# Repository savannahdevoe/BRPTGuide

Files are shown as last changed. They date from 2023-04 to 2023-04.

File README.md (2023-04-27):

# BRPTGuide
How-to-guide, user manual, and miscellaneous files to construct and operate a BRPT (Blue Robotics Pressure and Temperature) instruments for measuring water temperature (C) and pressure (mbar). The BRPT samples at a rate of ~16 Hz and may be deployed (in its current design) for a period of 4-10 days (depending on battery capacity and environmental conditions) in up to 10 m of water depth. Original instrument designed, fabricated, and tested by Spencer Marquardt, M.S. (UNH '22G).

PLEASE READ THE DISCLAIMERS AT THE END OF THIS README.

PURPOSE: This repository contains information and instructions on how to construct and operate a novel pressure/temperature instrument to collect environmental data. BRPTs have primarily been utilized and tested in nearshore/wave-current climates to observe swash zone, wave, and flooding dynamics. The BRPT may also be appropriate for other applications and in various environments.

FILES: This repository contains the following directories.
  Arduino        — This directory contains the Arduino .ino sketch to control the Teensy microcontroller and BlueRobotics sensors. The associated libraries                    (for the pressure and temperature sensor) are also included. Source code in these libraries has been modified to work with the BRPT .ino                    sketch.
  AssemblyGuide  - This directory contains the overview document for how to construct the BRPT and its various components. Note, this assembly guide                          provides instructions for creating BRPTs using the 1ST GENERATION BlueRobotics acrylic Series 3 housing and end caps, which has been                        DISCONTINUED at the time of upload. Document needs to be updated to reflect newer designs using 2nd Generation BlueRobotics housings and                    end caps and/or custom housing designs using PVC or other material.
  CAD_3DPrinting - This directory contains CAD files to generate a 3D SolidWorks model of the BRPT with the 1ST GENERATION acrylic housing and end caps.                      Files are also included for the 3D-printed components required to assemble the battery housing. CAD drawings are provided to show                          modifications required for the BlueRobotics end caps (3 hole end cap plate is CUSTOM machined part) and the BlueRobotics 1st Gen housing                    (to add threaded inserts to the end walls for more secure fastening of end caps to the housing body, as well as boring out the inner                        diameter of the 1st Gen housing to ensure a uniform contact surface for the end cap o-rings).
  OpsManual      - This directory contains the operations manual ("Quick Start Guide") providing instructions for how to prepare the circuit, battery                          housing, external housing, and end caps for deployment of the 1ST GENERATION acrylic housing BRPT. The document also briefly explains                      the data retrieval and conversion process at the conclusion of data collection.
  PartsList      - This directory contains a spreadheet of materials required to construct the BRPTs. It has been updated to reflect materials required for                    the NEW 2ND GENERATION locking-flange acrylic housings and end caps provided by BlueRobotics at the time of publication (April 2023). T                    This list should be reviewed thoroughly by the user prior to being utilized to purchase supplies to construct a BRPT.
  PCB            - This directory contains the files required to print a custom printed circuit board.
  SLERJ_Logger   - This directory contains information about the multi-channel serial datalogger used in the BRPT, including a general setup and data                          conversion guide. A brief overview of the specific steps required for setup and data conversion with the BRPTs is also included in the                      Quick Start Guide in the OpsManual directory.

DISCLAIMERS:
1. THIS REPOSITORY IS STILL BEING EDITED, UNLESS NOTED OTHERWISE.
2. All files (guides, documents, codes, etc.) in this repository may contain unintentional errors and should be considered as DRAFT documents. Please thoroughly review them and follow instructions or suggestions at your own discretion.
3. Instructions and designs contained herein are works in progress, and as such, span a range of part generations, design iterations, etc. and are not finalized unless noted otherwise.
4. This repository is meant to serve as an educational resouce for the construction of BRPT (pressure/temperature) instruments and is not intended to provide a foolproof, commercial-quality instrument. 

Thank you in advance for your interest and understanding!
Savannah DeVoe
Coastal Processes Lab
School of Marine Science & Ocean Engineering
University of New Hampshire

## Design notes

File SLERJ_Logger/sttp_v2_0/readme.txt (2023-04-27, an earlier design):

Version 2.0 - 2 Mar 2019 (see changelog below)

The SLERJ Time Tagged Parser is a Windows command line utility (sttp.exe) 
provided with the SSR loggers to parse time tagged archives into various
output types.  Given a time tagged archive, the utility can produce a
variety of output files including:
  => the original raw stream (with no timing information),
  => timestamped text lines (for archives of recorded text data),
  => and detailed contents of the archive to include:
     - a time correlation packet file,
     - a data packet file that has a line for each data frame,
     - and a mixed file that interlaces time correlation with data packets.

***** NEW WITH VERSION 2.0 *****
Version 2 of STTP now supports user defined scripts to parse payload data
with reference to the SSR timestamps embedded in time tagged archives.
Check out the Lua scripts in the examples subfolder.

For timestamped-line output, the format of the time stamp can be specified
using any of the identifiers used by the standard C89 library function strftime.
A list is provided below for reference.

For the detailed archive content output (options -t, -d, and -m), data bytes 
are represented as a series of hexadecimal text characters. An example of each 
of the output files is below.   Usage of the sttp utility is summarized by 
its help output:

usage: sttp.exe [options] <infile>
    Version 2.0, Mar  2 2019 11:05:21
    options:
      -h                Include headers in tcp and dat files.
      -r <raw_file>     Write raw stream data to raw_file
      -x <lua_file>     Send data to an external lua script for parsing
      -t <tcp_file>     Write Time Correlation Packets to tcp_file
      -d <dat_file>     Write Tagged data to dat_file
      -m <mxd_file>     Write both TCPs and tagged data to mxd_file
      -n <txt_file>     Write timestamped line text file
      -N "string"       Date format string for tagged line output (strftime)
      -S                Suppress milliseconds in tagged line output
      --nointerp        Use pre-v1.6 behavior, not interpolating timestamps in -n output
      --dat-bpl         Modified Tagged data (-d) output to give one data byte per line
    Interval extraction options for timestamped line output:
         For the arguments below, 'N' is assumed to be in seconds unless suffixed with 'L', which
         denotes lines.  For example '-i 30' denotes an interval of 30 seconds, where '-i 30L' denotes
         an interval of 30 timestamped lines of data.
      -k,--skip N       Skip N seconds/lines of data before producing output
      -i,--interval N   Extract excerpts at intervals of N seconds/lines
      -w,--window N     Extract N seconds/lines at each interval
      -v,--nwins M      Process M windows (default=0, which means to end of file)

Timestamped-line text output:
  Note that for timestamped-line output, each line that contains data will be
  prepended by a date string as determined by the specified format (or the
  default format "%Y %m %d %H %M %S "), followed by the three digit millisecond
  portion of the timestamp, followed by the contents of the line.  The time
  stamp prepended to the line corresponds to the time of the 2ms cycle in
  which the first character of the line was received.

  Consider an example in which the following text output is recorded:
    S D  0.0000122 kg
    S D  0.0000122 kg
    S D  0.0000122 kg
    S D  0.0000123 kg

  Timestamped-line text output example using the default format:
    2014 02 03 21 47 38 915 S D  0.0000122 kg
    2014 02 03 21 47 39 013 S D  0.0000122 kg
    2014 02 03 21 47 39 111 S D  0.0000122 kg
    2014 02 03 21 47 39 207 S D  0.0000123 kg

  Timestamped-line text output example using -N "%m/%d/%Y %H:%M:%S.":
    02/03/2014 21:47:38.915 S D  0.0000122 kg
    02/03/2014 21:47:39.013 S D  0.0000122 kg
    02/03/2014 21:47:39.111 S D  0.0000122 kg
    02/03/2014 21:47:39.207 S D  0.0000123 kg

Time Correlation Packet output example:
    RunTime(ms) Year Month Day Hour Minute Second
    4196 2013 3 25 9 52 4.625
    604196 2013 3 25 10 2 3.628
    1204196 2013 3 25 10 12 2.486

Tagged Data output example:
    RunTime(ms) count HexBytes
    4196 20 322E323530333630652B303520322E3339343433
    4198 23 30652D3034202D312E343530303639652D303420322E37
    4200 23 3637343235652D303420312E373134373036652D303120

Mixed output example:
    A3 4196 2013 3 25 9 52 4.625
    A2 4196 20 322E323530333630652B303520322E3339343433
    A2 4198 23 30652D3034202D312E343530303639652D303420322E37
    …
    A2 604194 23 3032202D352E353633313634652D303120312E32323636
    A3 604196 2013 3 25 10 2 3.628
    A2 604196 23 3330652D303220332E313334343333652B303020302037

Timestamped-line mode format options
  For timestamped-line mode, the specific form of the timstamp may be specified
  on the command line with the -N option.  For example, to add a timestamp of
  the form yyyy-mm-dd hh:mm:ss.msec, add to the command line:
     -N "%Y-%m-%d %H:%M:%S."
  The % fields are the same as those defined for the standard C library
  function strftime.  The most common are listed below.  Unless -S is specified
  on the sttp command line to suppress the milliseconds field, the three digit 
  value of milliseconds will immediately follow the result of the format string.  
  In the example above, the period at the end of the string serves as the  
  decimal in the fractional seconds field that results.  An example of lines  
  generated using this format string and no -S would be:
      2014-02-03 21:47:38.915 S D  0.0000122 kg
      2014-02-03 21:47:39.013 S D  0.0000122 kg
      2014-02-03 21:47:39.111 S D  0.0000122 kg
      2014-02-03 21:47:39.207 S D  0.0000123 kg

  Common timestamp format fields:
   Field Example
    %b   Aug                       Abbreviated month name
    %B   August                    Full month name
    %c   Thu Aug 23 14:55:02 2001  Date and time representation
    %d   23                        Day of the month, zero-padded (01-31)
    %H   14                        Hour in 24h format (00-23)
    %I   02                        Hour in 12h format (01-12)
    %j   235                       Day of the year (001-366)
    %m   08                        Month as a decimal number (01-12)
    %M   55                        Minute (00-59)
    %p   PM                        AM or PM designation
    %S   02                        Second (00-61)
    %x   08/23/01                  Date representation
    %X   14:55:02                  Time representation
    %y   01                        Year, last two digits (00-99)
    %Y   2001                      Year
    %%                             A % sign  %

In version 2, the -x option has been added to send the packet data to a Lua
script for parsing.  The script must define the function:
  ParseData(runtime,timestamp,data)
The lua script is executed when it is loaded, allowing parser state to be 
initialized and output file(s) to be opened as required.  Then the ParseData
function will be called for each time tagged data packet in the archive, and
will receive the packet runtime (in msec), a formatted timestamp based on the
SSR real time clock using the provided strftime format string, and the bytes
stored in the time tagged data packet.

The Lua Environemnt provides a couple of additional functions that can
reach back into STTP.
  sttp_setTSFormat(string fmt, bool SuppressMSec)
      This function allows the timestamp format string to be provided in
      the lua script instead of on the sttp command line using -N.  The
      second argument replaces the command line argument -S.  This function
      overrides the command line arguments.
  sttp_getPaths()
      This function returns a table with useful path information.  Fields
      of the table are:
      ArchiveFile - the full, absolute path of the archive file being parsed
      ArchivePath - the directory of the archive file
      ArchiveName - the name of the archive file (without path or extension)
      ArchiveExt  - the archive file extension
      cwd         - the STTP current working directory.

See the Lua examples for details on how to use these. 

==============================================================================
ChangeLog
---------
Version 2.0 - 2 Mar 2019
  Added Lua script engine to support external, application specific data
  parsers.  This allows binary data stored in a time tagged archive to be
  parsed with the SSR clock information available for reference.  See the
  lua examples for detials.

Version 1.7 - 7 Feb 2019
  Added an option --dat-bpl to change the -d (dat file) output to give
  one byte per line so that each line has only RunTime and a single byte.
  
Version 1.6 - 15 Mar 2018
  Reworked timestamped-line output to interpolate the RTC based timestamp to 
  compensate for drift of the free running msec clock used to tag data packets.

  Added the option --nointerp to revert to the original behavior. 
  
Version 1.5 - 21 Feb 2018
  Added support for time tagged archives recorded at high data rates and
  bandwidth (>635 kbaud).  This corresponds to a fix in SSR-1 firmware
  v1.2.1.

Version 1.4 - 10 Aug 2017
  Added options to decimate timestamp line output (only output at intervals).
  
Version 1.3 - 4 Feb 2017
  Corrected bug that caused high baud recordings (>315k baud) to fail parsing.
  
Version 1.2 - 10 May 2016
  Corrected bug where -n option was looking for 0xC as newline instead of 0xD
  
Version 1.1 - 19 Feb 2015
  Added timestamped-line mode for text data recorded in an archive.

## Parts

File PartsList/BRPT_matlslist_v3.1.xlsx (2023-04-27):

DISCLAIMER: THIS SHEET CONTAINS A MIXTURE OF SUGGESTED AND REQUIRED MATERIALS TO CONSTRUCT THE BRPT INSTRUMENT. Prices and availability shown as of September 2022. Items should be purchased at your own discretion. Cells and prices are meant to change automatically depending on the number of NEW BRPTs you want to make (specified in J6) and spare circuitry/battery components you wish to make (specified in J2), but should be verified by the reader prior to making purchases. |  |  |  |  |  |  |  | SPARES? | 2 | num of spare circuitry components (e.g., sensors, PCBs, etc.)
Rev 2.0 | Savannah DeVoe | 2023-04-01
Item # | Note and/or BRPT Version | Part Name | Part Description | Company | PartNnumber (SKU) | Price | Unit | QTY Have | QTY Need | QTY To Purchase | Subtotal | Link
1 | INPUT QTY OF BRPTs YOU WANT TO MAKE IN THIS ROW, AND ALL OTHERS SHOULD POPULATE | Acrylic Pipe | 3" series cast acrylic 300mm (11.8") length, 150 m depth rating, 75mm (3") dia. | Blue Robotics | WTE3-P-LOCKING-TUBE-300-R2-RP | $215.00 | /EA | 0 | 2 | 2 | $430.00 | https://bluerobotics.com/store/watertight-enclosures/locking-series/wte-locking-tube-r1-vp/
2 | v3.1 only | O-Ring Flange | 75 mm (3") dia., comes with o-rings and screws | Blue Robotics | WTE3-M-LOCKING-FLANGE-SEAL-R1-RP | $35.00 | /EA | 0 | 4 | 4 | $140.00 | https://bluerobotics.com/store/watertight-enclosures/locking-series/wte-flange-vp/
3 | CHOOSE EITHER 3 OR 4. v3.1 and v3.2 | Blank Acrylic End Cap | End Cap - Acrylic - Blank - 400 m 75 mm (3") dia. | Blue Robotics | WTE3-P-END-CAP-R1-RP | $15.00 | /EA | 0 | 0 | 0 | $0.00 | https://bluerobotics.com/store/watertight-enclosures/locking-series/wte-end-cap-vp/
4 |  | Blank Aluminum End Cap | End Cap - Aluminum - Blank - 950 m 75 mm (3") dia. | Blue Robotics | WTE3-M-END-CAP-R1-RP | $14.00 | /EA | 0 | 8 | 8 | $112.00 | https://bluerobotics.com/store/watertight-enclosures/locking-series/wte-end-cap-vp/
5 | Not a totally necessary part (we machine item 2 or 3 to have 3 holes) but it's here for reference. V3.1 and v3.2 | 4 Hole Aluminum End Cap | End Cap - Aluminum - 4 Holes - 950 m 75 mm (3") dia. | Blue Robotics | WTE3-M-END-CAP-4-HOLE-R1-RP | $14.00 | /EA | 0 | 0 | 0 | $0.00 | https://bluerobotics.com/store/watertight-enclosures/locking-series/wte-end-cap-vp/
6 | NOTE: This part optional. We will use backflow prevention valves (see below) instead of the enclosure vent and plug for Foster Lab BRPTsv3.1 and v3.2 | Enclosure Vent and Plug | M10 Enclosure Vent and Plug | Blue Robotics | VENT-M10-R1-RP | $9.00 | /EA | 0 | 4 | 4 | $36.00 | https://bluerobotics.com/store/cables-connectors/penetrators/vent-asm-r1/
7 | v3.1 and v3.2 | Pressure Sensor | Bar02 Ultra High Resolution 10m Depth/Pressure Sensor | Blue Robotics | BAR02-SENSOR-R2-RP | $75.00 | /EA | 0 | 4 | 4 | $300.00 | https://bluerobotics.com/store/sensors-sonars-cameras/sensors/bar02-sensor-r1-rp/
8 | v3.1 and v3.2 | Temperature Sensor | Celsius Fast-Response, ±0.1°C Temperature Sensor (I2C) | Blue Robotics | CELSIUS-SENSOR-R2-RP | $70.00 | /EA | 0 | 4 | 4 | $280.00 | https://bluerobotics.com/store/sensors-sonars-cameras/sensors/celsius-sensor-r1/
9 | NOTE: This part optional. We will use backflow prevention valves (see below) instead of the enclosure vent and plug for Foster Lab BRPTsv3.1 and v3.2 | Manual Vacuum Pump | Mityvac Hand Operated Vacuum Pump | Blue Robotics | VACUUM-PUMP-KIT-R4-RP | $98.00 | /EA | 0 | 0 | 0 | $0.00 | https://bluerobotics.com/store/watertight-enclosures/enclosure-tools-supplies/vacuum-pump-kit-r2-rp/
10 | NOTE: This part optional. We will use backflow prevention valves (see below) instead of the enclosure vent and plug for Foster Lab BRPTsv3.1 and v3.2 | Vacuum Plug | Adapter for vacuum pump | Blue Robotics | VENT-M10-VACUUM-PLUG-R1-RP | $8.00 | /EA | 0 | 0 | 0 | $0.00 | https://bluerobotics.com/store/watertight-enclosures/enclosure-tools-supplies/vacuum-plug/
11 | v3.1 only | Spare Locking Cord and Handles |  | Blue Robotics | WTE-LOCKING-CORD-SPARE-SET-R1-RP | $10.00 | /EA | 0 | 1 | 1 | $10.00 | https://bluerobotics.com/store/watertight-enclosures/locking-series/wte-locking-cord/
12 | v3.1 and v3.2 | Spare O-Ring Set | Spare O-ring Set 75 mm (3") dia. | Blue Robotics | WTE3-O-RING-SET-R2-RP | $3.00 | /EA | 0 | 2 | 2 | $6.00 | https://bluerobotics.com/store/watertight-enclosures/locking-series/spare-o-ring-set/
13 | v3.1 and v3.2 | Datalogger | SSR-LC Single Channel Serial Data Logger | SLERJ | SSRLC | $39.00 | /EA | 0 | 4 | 4 | $156.00 | https://www.slerj.com/ssr-lc.html
14 | v3.1 and v3.2 | microSD card | SanDisk Industrial MLC MicroSD SDHC UHS-I Class 10 SDSDQAF3-008G-I with SanDisk Adapter (8GB) | SanDisk; purchased via Amazon |  | $9.10 | /EA | 0 | 4 | 4 | $36.40 | https://www.amazon.com/SanDisk-Industrial-MicroSD-SDSDQAF3-008G-I-Adapter/dp/B07BZ5SY18
15 | v3.1 and v3.2. NOTE: 3D-printed battery holders are designed for particular battery length. | Batteries | 18650 2600mAH 3.7V battery | Dantona Industries; purchased via DigiKey | 3145-LION-1865-26-ND | $6.60 | /EA | 0 | 48 | 48 | $316.80 | https://www.digikey.com/en/products/detail/dantona-industries/LION-1865-26/13692661
16 | v3.1 and v3.2 | Voltage Regulator | IC Reg linear 5V 1.5A TO220-3 | DigiKey | Digi-Key Part Number: 296-39515-5-ND | $0.87 | /EA | 0 | 8 | 8 | $6.96 | https://www.digikey.com/en/products/detail/texas-instruments/UA7805CKCT/3458146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
17 | v3.1 and v3.2 | Battery Springs | Battery contact spring | DigiKey | 36-209-ND | $0.22 | /EA | 0 | 96 | 96 | $21.12 | https://www.digikey.com/en/products/detail/209/36-209-ND/151583?itemSeq=362037172
18 | v3.1 and v3.2 | On-Off Button | Tactile Switch Buttons (12mm square, 6mm tall) x 10 pack | Adafruit | 1119 | $2.50 | /EA | 0 | 1 | 1 | $2.50 | https://www.adafruit.com/product/1119
19 | v3.1 and v3.2 | Coin Cell Battery Board | 20mm Coin Cell Breakout Board (CR2032) | Adafruit | 1870 | $2.25 | /EA | 0 | 4 | 4 | $9.00 | https://www.adafruit.com/product/1870
20 | v3.1 and v3.2 | Teensy | Teensy 4.0 Microcontroller | Adafruit, purchased via DigiKey | Digi-Key Part Number: 1568-DEV-15583-ND | $21.88 | /EA | 0 | 4 | 4 | $87.52 | https://www.digikey.com/en/products/detail/sparkfun-electronics/DEV-15583/10384551
21 | v3.1 and v3.2 | Coin Cell Battery | CR2032 3.0V LITHIUM - PACK OF 5 | PKCell; purchased via DigiKey | 2375-CR2032-5B-ND | $1.00 | /EA | 0 | 1 | 1 | $1.00 | https://www.digikey.com/en/products/detail/pkcell/CR2032-5B/11629990
22 | v3.1 and v3.2 | Sensor Cable GH Connectors/Plugs | CQRobot 100 Sets/600 Pieces JST GH 1.25mm Pitch 4 Pin JST Connector Kit. JST 1.25mm Pitch Terminals, JST GH 4 Pin Housing JST Adapter Cable Connector Socket Male and Female, Crimp DIP Pins kit. | CQRobot, purchased via amazon | JST-GH1.25 GH 4P | $11.69 | /EA | 0 | 1 | 1 | $11.69 | https://www.amazon.com/CQRobot-Connector-Terminals-Housing-Adapter/dp/B0B3NB2PM8
23 | v3.1 and v3.2 | Battery/Jumper Cable JST Connectors/Plugs | 720Pcs 2.54mm JST-XHP 2/3 / 4/5 Pin Housing and Male Female Pin Header Connector Adapter Plug Set | FUNMANY; purchased via Amazon |  | $13.99 | /EA | 0 | 1 | 1 | $13.99 | https://www.amazon.com/gp/product/B0752C431F/ref=ox_sc_act_title_1?smid=A6QA7SV6MW7GH&psc=1
24 | v3.1 and v3.2 | Threaded Rod | 8-32 x 7" low-strength steel threaded rods, pk of 10 | McMaster-Carr | 91565A345 | $7.88 | /EA | 0 | 1 | 1 | $7.88 | https://www.mcmaster.com/91565A345/
25 | v3.1 and v3.2 | Wing Nut | 8-32x5/8x7/8 zinc alloy flanged wing nut, pk of 25 | McMaster-Carr | 92239A100 | $11.18 | /EA | 0 | 1 | 1 | $11.18 | https://www.mcmaster.com/92239A100/
26 | v3.1 and v3.2 | Standoff Screws | 4-40x1/2" long 3/16" aluminum male-female threaded hex standoff | McMaster-Carr | 93505A103 | $0.43 | /EA | 0 | 8 | 8 | $3.44 | https://www.mcmaster.com/93505A103/
27 | v3.1 and v3.2 | Flat Head Screws | 4-40x1/2" long 18-8 Stainless Steel Slotted Flat Head Screw, pk of 100 | McMaster-Carr | 91781A110 | $5.81 | /EA | 0 | 1 | 1 | $5.81 | https://www.mcmaster.com/91781A110/
28 | v3.1 and v3.2 | Hex Nut | 4-40 18-8 Stainless Steel Narrow Hex Nut, pk of 100 | McMaster-Carr | 90730A005 | $4.21 | /EA | 0 | 1 | 1 | $4.21 | https://www.mcmaster.com/90730A005/
29 | not really necessary (they come with the end caps), but good to have; v3.1 and v3.2 | End Cap Screw Replacements | M3x0.5-12 18-8 stainless steel socket head screw, pk of 100 | McMaster-Carr | 91292A114 | $6.00 | /EA | 0 | 0 | 0 | $0.00 | https://www.mcmaster.com/91292A114/
30 | v3.1 and v3.2 | End Cap Tap Screws | 4-40x3/4" long 18-8 stainless steel socket head screw, pk of 100 | McMaster-Carr | 92196A113 | $7.33 | /EA | 0 | 1 | 1 | $7.33 | https://www.mcmaster.com/92196A113/
31 | v3.1 and v3.2 | Threaded Inserts | 18-8 Stainless Steel Helical Insert, 4-40 Right-Hand Thread, 0.168" Long, pk of 10 | McMaster-Carr | 91732A285 | $5.70 | /EA | 0 | 2 | 2 | $11.40 | https://www.mcmaster.com/91732A285/
32 | v3.1 and v3.2 | Heat Shrink Tubing | Ginsco 580 pcs 2:1 Heat Shrink Tubing Kit 6 Colors 11 Sizes Assorted Sleeving Tube Wrap Cable Wire Kit for DIY | Ginsco, purchased via Amazon |  | $6.20 | /EA | 0 | 1 | 1 | $6.20 | https://www.amazon.com/Ginsco-580-pcs-Assorted-Sleeving/dp/B01MFA3OFA
33 | v3.1 and v3.2 | Resistors | EDGELEC 100pcs 10K ohm Resistor 1/4w (0.25 Watt) ±1% Tolerance Metal Film Fixed Resistor, Multiple Values of Resistance Optional | EDGELEC, purchased via Amazon | [E6P011] 10K ohm | $4.99 | /EA | 0 | 1 | 1 | $4.99 | https://www.amazon.com/EDGELEC-Resistor-Tolerance-Resistance-Optional/dp/B07HDGX5LM
34 | Note, exact cost per board is approximate and changes based on number ordered; v3.1 and v3.2 | PCB | Printed Circuit Board, multiples of 3 | Print on Aisler.net; Fritzing file is BRPT_v1.fzz; or gerber file is in BRPT_gerber.zip |  | $11.00 | /EA (mult of 5) | 0 | 2 | 2 | $22.00 | https://www.jlcpcb.com
35 | v3.1 and v3.2 | Wire | Striveday™Flexible Silicone Wire 22awg Electric Wire 22 Gauge Coper Hook Up Wire 300V Cables Electronic Stranded Wire Cable Electrics DIY Box-1 | Striveday, purchased via Amazon |  | $15.99 | /EA | 0 | 1 | 1 | $15.99 | https://www.amazon.com/StrivedayTM-Flexible-Silicone-electronic-electrics/dp/B01LH1FR6M
36 | this cable to be modified, used to connect circuit to PC; v3.1 and v3.2 | USB Cable | UGREEN USB to USB Cable, USB 3.0 Male to Male Type A to Type A Cable for Data Transfer Compatible with Hard Drive, Laptop, DVD Player, TV, USB 3.0 Hub, Monitor, Camera, Set Up Box and More 3FT | UGREEN, purchased via Amazon |  | $8.89 | /EA | 0 | 4 | 4 | $35.56 | https://www.amazon.com/dp/B00P0E39CM/ref=twister_B07CJ2Z4DZ?_encoding=UTF8&psc=1
37 | v3.1 and v3.2 | Epoxy | Structural Adhesive epoxy, Loctite 615 | McMaster Carr | 1813A246 | $18.26 | /EA | 0 | 1 | 1 | $18.26 | https://www.mcmaster.com/1813A246/
38 | v3.1 and v3.2 | Silicone sealant | Molykote 55 o-ring grease | McMaster-Carr | 1325K54 | $46.04 | /EA | 0 | 1 | 1 | $46.04 | https://www.mcmaster.com/1325K54/
39 | v3.1 and v3.2 | Battery charger | 8 Slots 18650 Battery Charger XTAR VC8 Charger USB C 3A Fast Charger 21700 Battery Charger with LCD Display for 3.6V 3.7V Li-ion 10440 18700 26650 1.2V Ni-MH AA AAA C Full Set with QC3.0 Wall Charger | XTAR, purchased via Amazon | VC8+QC3.0 Adapter | $40.00 | /EA | 0 | 2 | 2 | - | https://www.amazon.com/gp/product/B0836VHG67/ref=sw_img_1?smid=A3DHI68LB66BYX&th=1
40 | v3.1 and v3.2. NOTE: These used for particular deployment case. Different/additional materials are likely required for your particular deployment strategy. | Gasket sheet mcmaster |  |  | 1370N553 | $27.73 |  | 0 |  | 2 | 27.73
41 | v3.1 and v3.2. NOTE: These used for particular deployment case. Different/additional materials are likely required for your particular deployment strategy. | Screw anchors from amazon | MTB 30 Inches Auger Earth Anchor 3 Inches W Helix, 12mm Rod, Painted red, Heavy Duty Ground Anchor Hook for Guying Tents Fencing Canopies, Pack of 6 | Purchased via Amazon |  | $44.14 | /EA | 0 | 1 | 1 | 44.14 | https://www.amazon.com/MTB-Anchor-Painted-Fencing-Canopies/dp/B01MUZ9CLL
42 | v3.1 and v3.2. NOTE: These used for particular deployment case. Different/additional materials are likely required for your particular deployment strategy. | hose clamps | Worm-Drive Clamp for Firm Hose and Tube 316 Stainless Steel, 1/2" Band Width, 2-9/16"- 3-1/2" Clamp ID, pk of 5 | McMaster Carr | 5011T25 | $18.04 | /EA | 0 | 2 | 2 | $36.08 | https://www.mcmaster.com/5011T25/
43 | FOSTER LAB OPTION, v3.1 and v3.2 | Back Flow prevention valve | Brass Threaded Check Valve with Brass Spring-Loaded Piston, 1/8 NPTF Male | McMaster Carr | 7775K61 | $14.67 | /Ea | 0 | 4 | 4 | $58.68 | https://www.mcmaster.com/7775K61/
 |  |  |  |  |  |  |  | TOTAL COST: |  |  | $2131.23
 |  |  |  |  |  |  |  | UNIT COST |  |  | $1065.62

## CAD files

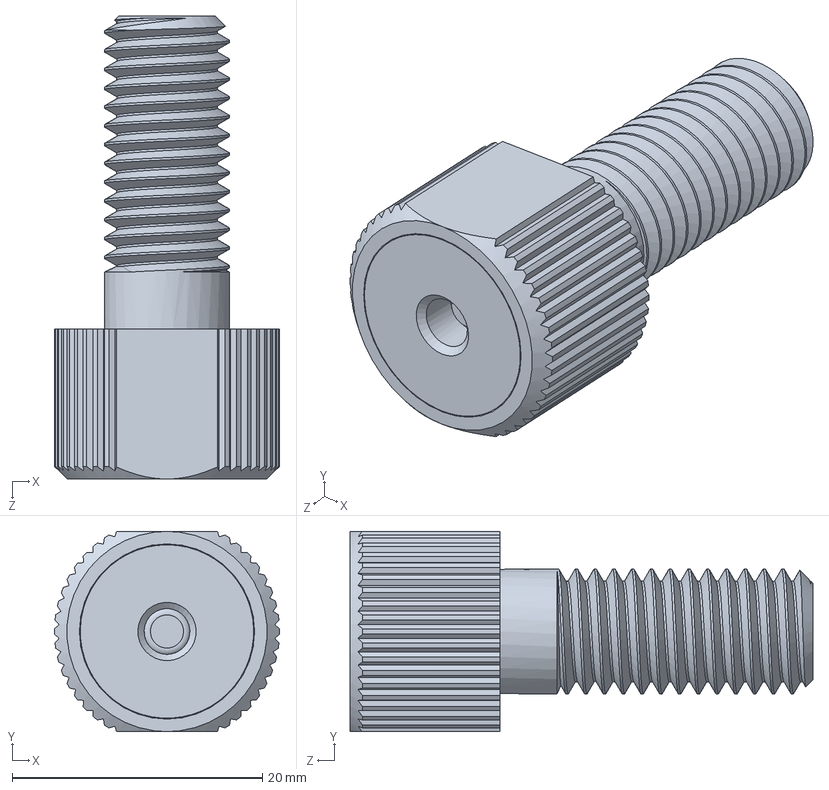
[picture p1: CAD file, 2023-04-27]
CAD_3DPrinting/Bar02/BAR30-SENSOR-ASSEMBLY-R1.SLDPRT
18.0 x 16.0 x 37.0 mm

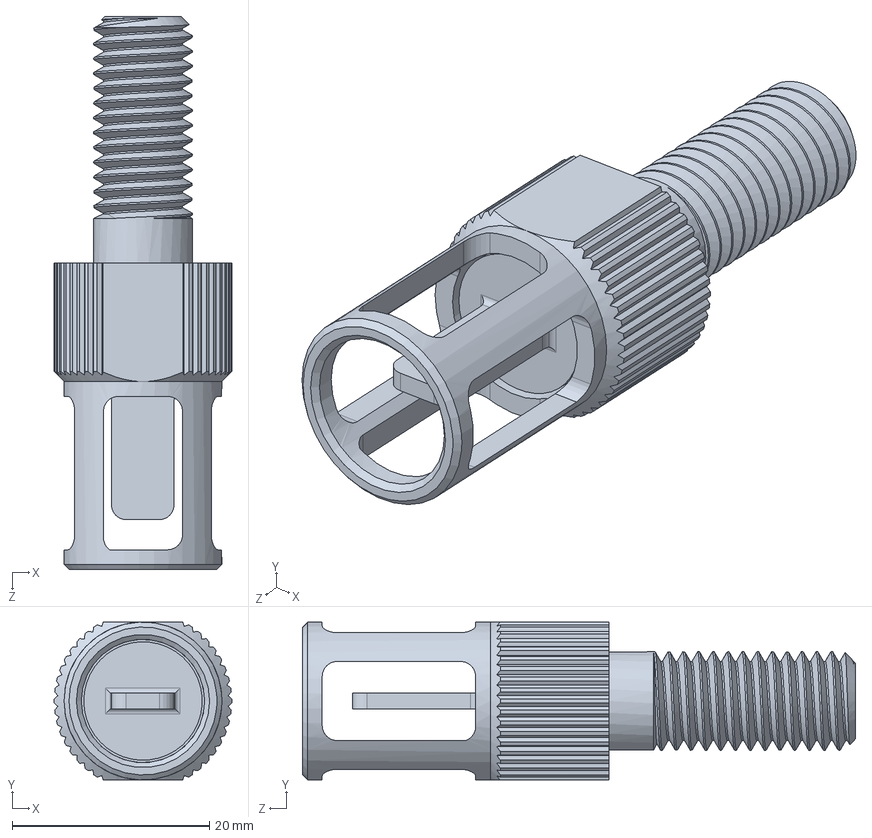
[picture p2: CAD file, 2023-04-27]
CAD_3DPrinting/Celcius temp sensor/CELSIUS-TEMPERATURE-SENSOR-ASSEMBLY-X1.SLDPRT
18.0 x 16.0 x 56.0 mm

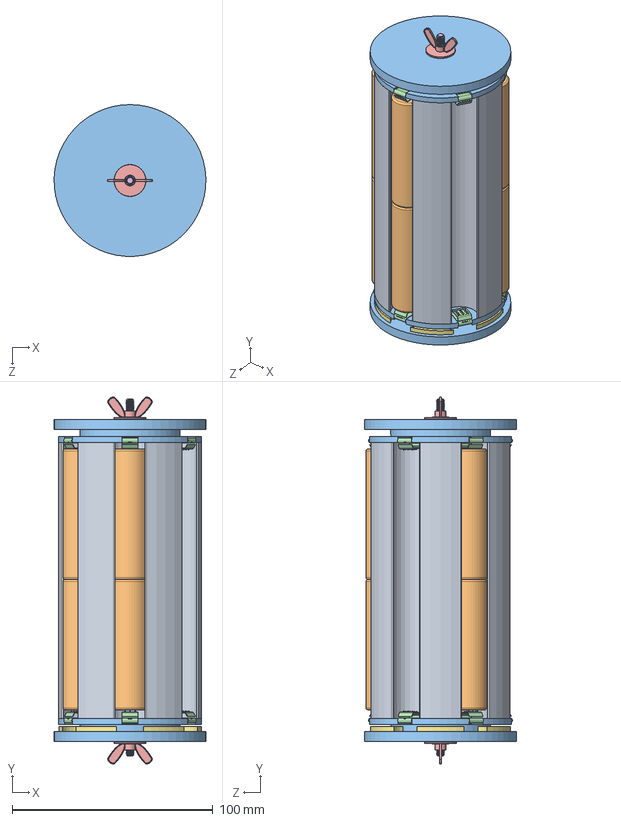
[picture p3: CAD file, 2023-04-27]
CAD_3DPrinting/Battery holder.SLDASM
75.7 x 182.9 x 75.7 mm
battery holder v2
2600mAh Battery x 8
Battery holder endcap x 2
battery contact 209 x 12
92239A100_FLANGED WING NUT x 2
91565A345_LOW-STRENGTH STEEL THREADED ROD

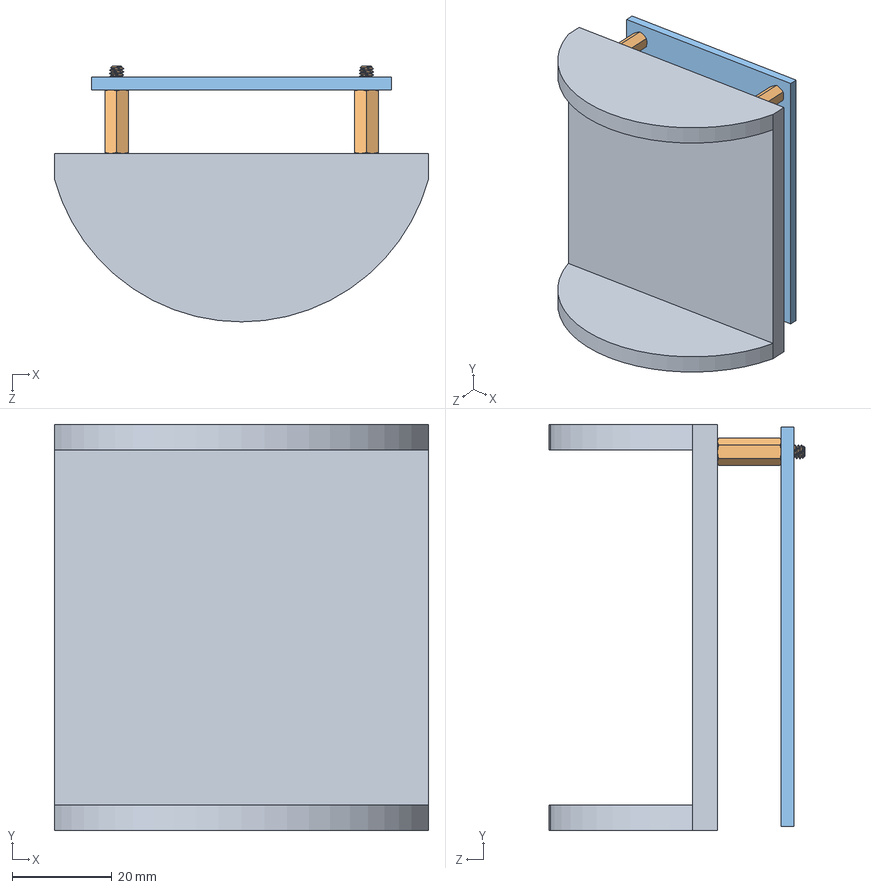
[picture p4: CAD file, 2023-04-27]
CAD_3DPrinting/Electronics Shelf.SLDASM
74.9 x 81.3 x 51.2 mm
Electronics Shelf
93505A103_MALE-FEMALE THREADED HEX STANDOFF x 2
PCB

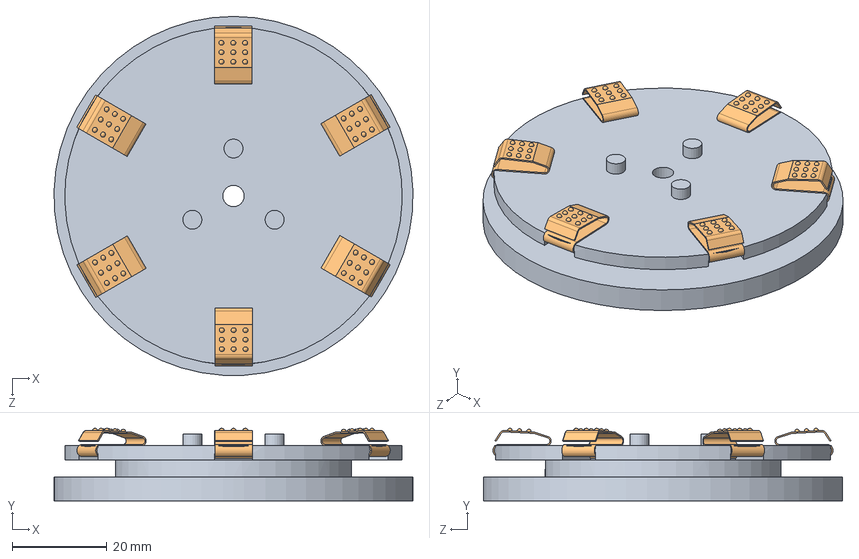
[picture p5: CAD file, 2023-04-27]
CAD_3DPrinting/Battery holder endcap.SLDASM
75.7 x 15.3 x 75.7 mm
Battery holder endcap
battery contact 209 x 6

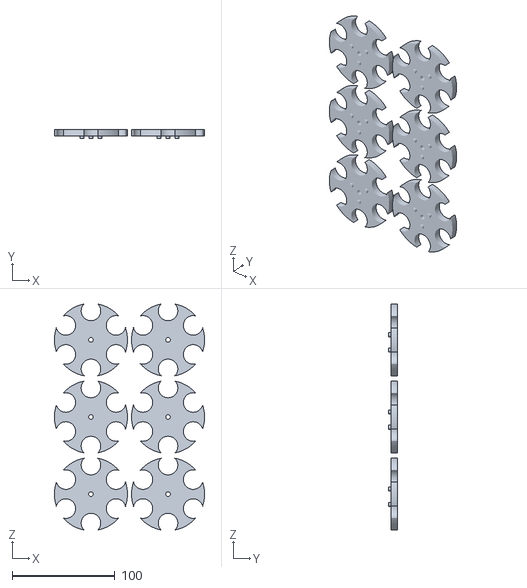
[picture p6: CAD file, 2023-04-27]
CAD_3DPrinting/3D print/Battery holder spacer 6.STL
146.1 x 9.00 x 219.8

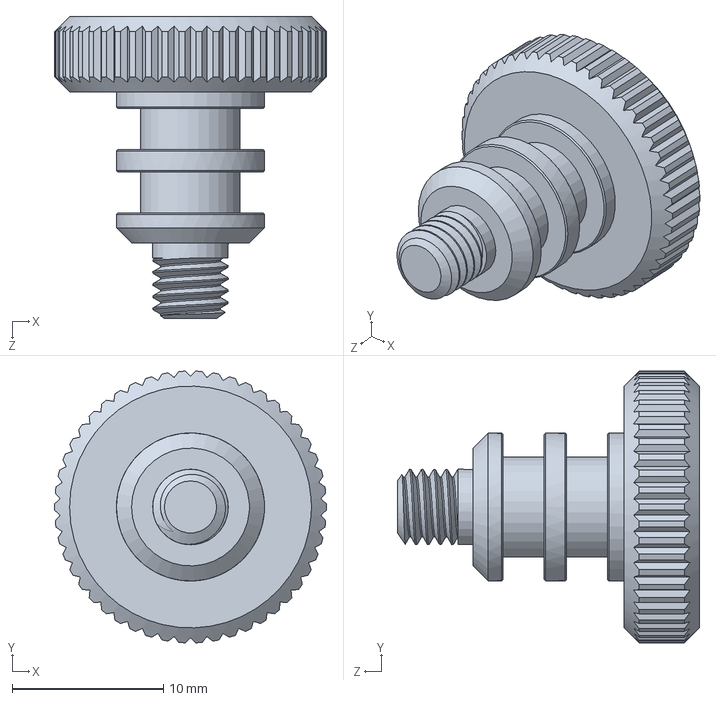
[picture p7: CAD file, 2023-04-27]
CAD_3DPrinting/vent/VENT-M-PLUG-10-A-R3.SLDPRT
18.0 x 18.0 x 20.0 mm

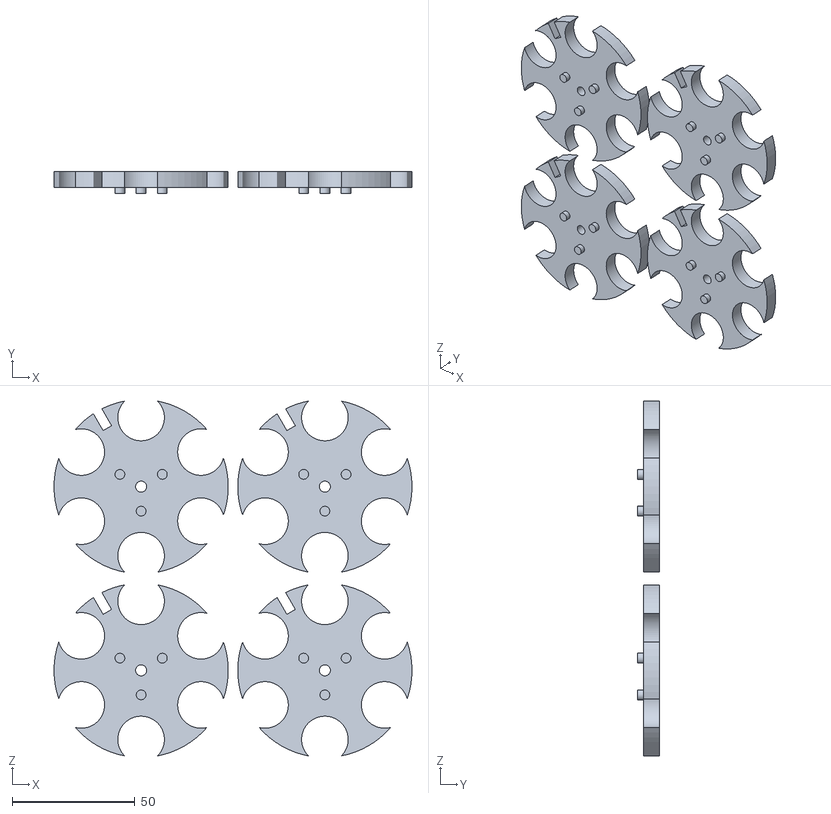
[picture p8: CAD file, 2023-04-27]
CAD_3DPrinting/3D print/Battery holder spacer 4.STL
146.1 x 9.00 x 144.8

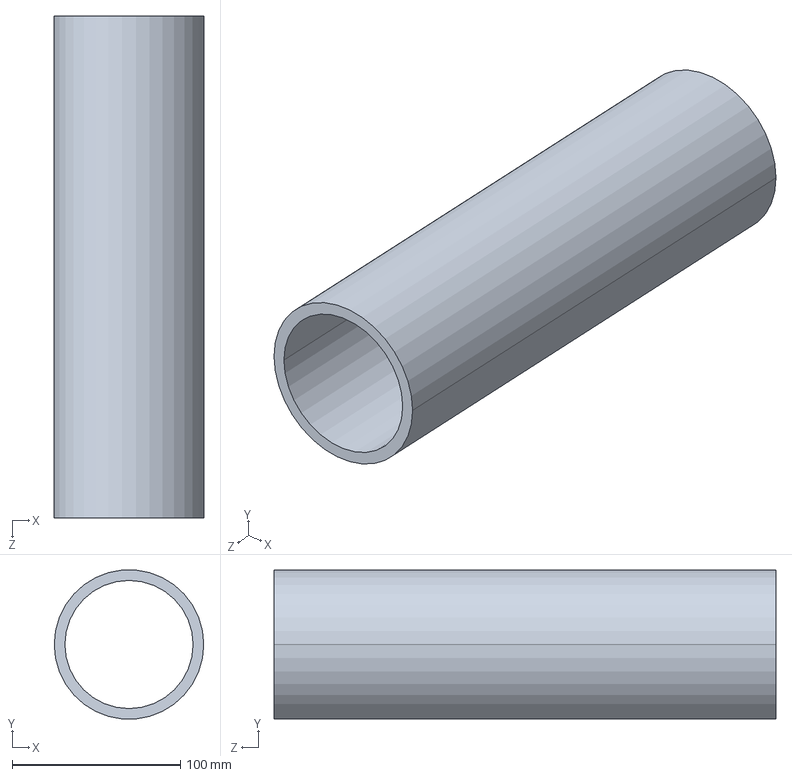
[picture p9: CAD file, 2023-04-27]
CAD_3DPrinting/WTE3-P-TUBE-12-R1.SLDPRT
88.9 x 88.5 x 298.4 mm

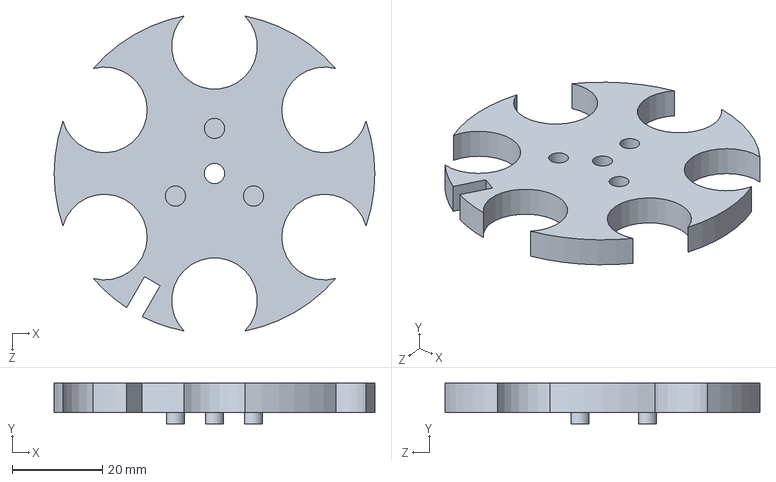
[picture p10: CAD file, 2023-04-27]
CAD_3DPrinting/Battery holder spacer.SLDPRT
71.1 x 9.00 x 69.8 mm

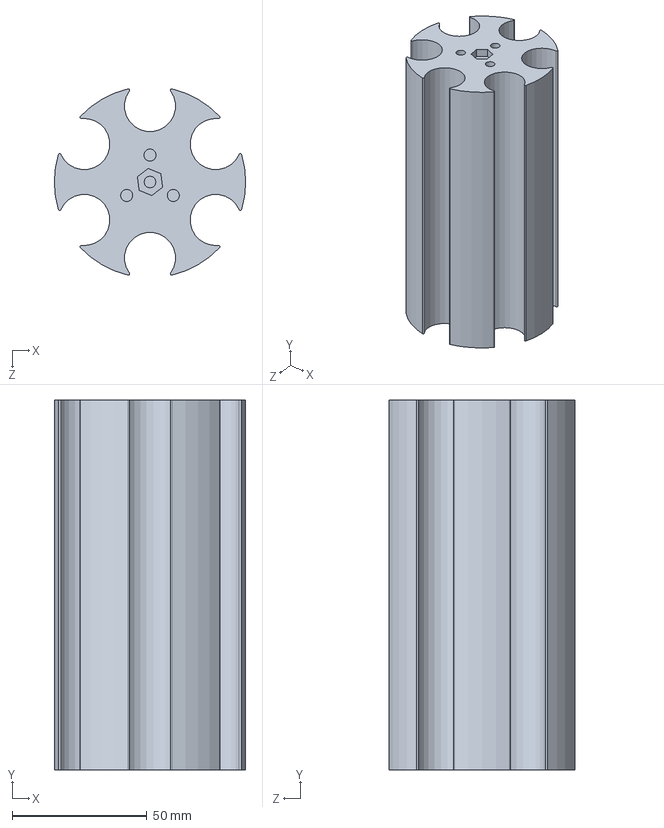
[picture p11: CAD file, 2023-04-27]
CAD_3DPrinting/battery holder v2.SLDPRT
71.1 x 137.5 x 69.2 mm

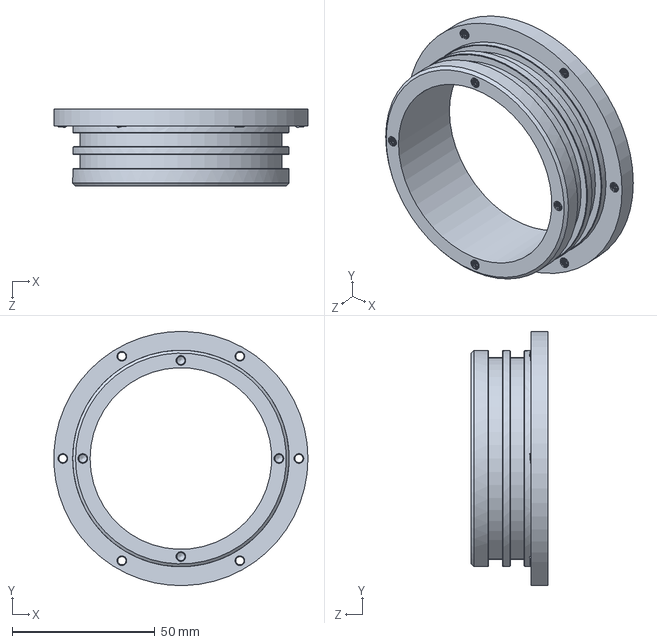
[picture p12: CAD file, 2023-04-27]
CAD_3DPrinting/3in series Oring flange.SLDPRT
88.8 x 88.9 x 27.0 mm

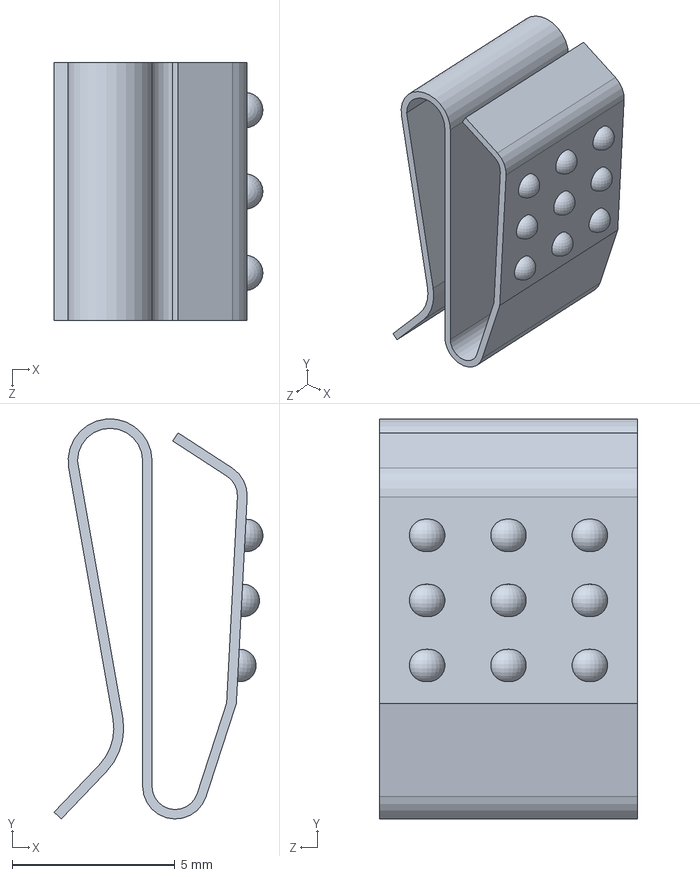
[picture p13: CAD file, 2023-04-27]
CAD_3DPrinting/battery contact 209.SLDPRT
6.42 x 12.3 x 7.92 mm

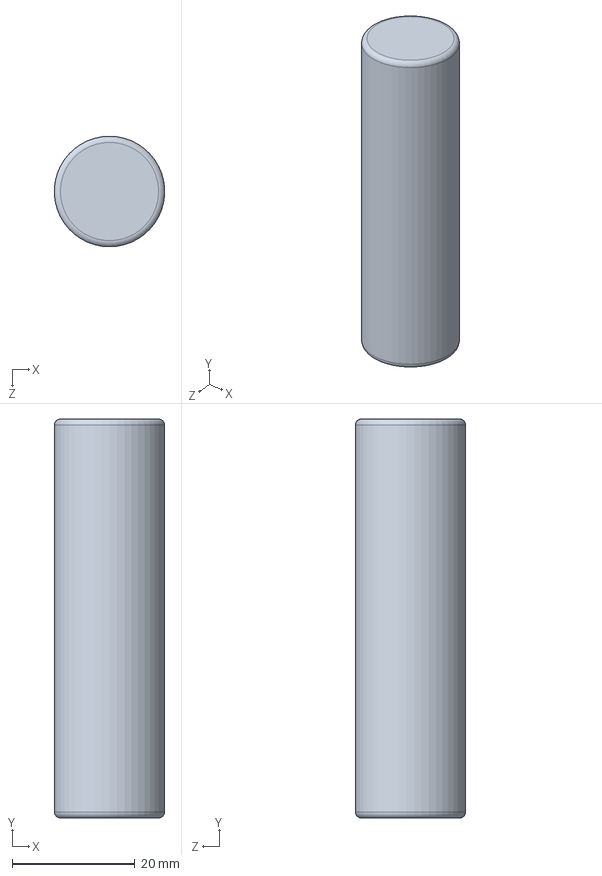
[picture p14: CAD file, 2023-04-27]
CAD_3DPrinting/2600mAh Battery.SLDPRT
18.0 x 65.0 x 18.0 mm

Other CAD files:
CAD_3DPrinting/3in series housing.SLDPRT
CAD_3DPrinting/PCB.SLDPRT
CAD_3DPrinting/3in series end cap 3 holes.SLDPRT
CAD_3DPrinting/3in series end cap.SLDPRT
CAD_3DPrinting/3D print/Battery holder endcap.STL
CAD_3DPrinting/3D print/Battery holder spacer.STL
CAD_3DPrinting/3D print/battery holder v2.STL
CAD_3DPrinting/8-32 075in_91781A197_18-8 SS FLAT HEAD SLOTTED MACHINE SCREW.SLDPRT
CAD_3DPrinting/8-32_90480A009_LOW-STRENGTH STEEL HEX NUT.SLDPRT
CAD_3DPrinting/91565A345_LOW-STRENGTH STEEL THREADED ROD.SLDPRT
CAD_3DPrinting/92239A100_FLANGED WING NUT.SLDPRT
CAD_3DPrinting/93505A103_MALE-FEMALE THREADED HEX STANDOFF.SLDPRT
CAD_3DPrinting/Bar02/PENETRATOR-M-NUT-10-8-R2.SLDPRT
CAD_3DPrinting/Battery holder endcap.SLDPRT
CAD_3DPrinting/Celcius temp sensor/PENETRATOR-M-NUT-10-8-R2.SLDPRT
CAD_3DPrinting/Electronics Shelf.SLDPRT
CAD_3DPrinting/battery holder.SLDPRT
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

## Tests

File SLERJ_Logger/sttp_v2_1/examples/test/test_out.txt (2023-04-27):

02/03/2014 21:47:38.915 S D  0.0000122 kg
02/03/2014 21:47:39.012 S D  0.0000122 kg
02/03/2014 21:47:39.110 S D  0.0000122 kg
02/03/2014 21:47:39.206 S D  0.0000123 kg
02/03/2014 21:47:39.304 S D  0.0000123 kg
02/03/2014 21:47:39.400 S D  0.0000123 kg
02/03/2014 21:47:39.498 S D  0.0000123 kg
02/03/2014 21:47:39.596 S D  0.0000123 kg
02/03/2014 21:47:39.692 S D  0.0000123 kg
02/03/2014 21:47:39.790 S D  0.0000123 kg
02/03/2014 21:47:39.886 S D  0.0000123 kg
02/03/2014 21:47:39.984 S D  0.0000123 kg
02/03/2014 21:47:40.082 S D  0.0000123 kg
02/03/2014 21:47:40.178 S D  0.0000124 kg
02/03/2014 21:47:40.276 S D  0.0000124 kg
02/03/2014 21:47:40.372 S D  0.0000124 kg
02/03/2014 21:47:40.470 S D  0.0000124 kg
02/03/2014 21:47:40.567 S D  0.0000124 kg
02/03/2014 21:47:40.663 S D  0.0000124 kg
02/03/2014 21:47:40.761 S D  0.0000124 kg
02/03/2014 21:47:40.859 S D  0.0000124 kg
02/03/2014 21:47:40.955 S D  0.0000125 kg
02/03/2014 21:47:41.053 S D  0.0000125 kg
02/03/2014 21:47:41.149 S D  0.0000125 kg
02/03/2014 21:47:41.247 S D  0.0000125 kg
02/03/2014 21:47:41.343 S D  0.0000125 kg
02/03/2014 21:47:41.441 S D  0.0000125 kg
02/03/2014 21:47:41.539 S D  0.0000125 kg
02/03/2014 21:47:41.635 S D  0.0000126 kg
02/03/2014 21:47:41.733 S D  0.0000126 kg
02/03/2014 21:47:41.829 S D  0.0000126 kg
02/03/2014 21:47:41.927 S D  0.0000126 kg
02/03/2014 21:47:42.025 S D  0.0000126 kg
02/03/2014 21:47:42.120 S D  0.0000127 kg
02/03/2014 21:47:42.218 S D  0.0000127 kg
02/03/2014 21:47:42.316 S D  0.0000127 kg
02/03/2014 21:47:42.412 S D  0.0000127 kg
02/03/2014 21:47:42.510 S D  0.0000127 kg
02/03/2014 21:47:42.608 S D  0.0000128 kg
02/03/2014 21:47:42.706 S D  0.0000128 kg
02/03/2014 21:47:42.804 S D  0.0000128 kg
02/03/2014 21:47:42.900 S D  0.0000128 kg
02/03/2014 21:47:42.998 S D  0.0000129 kg
02/03/2014 21:47:43.096 S D  0.0000129 kg
02/03/2014 21:47:43.192 S D  0.0000129 kg
02/03/2014 21:47:43.290 S D  0.0000130 kg
02/03/2014 21:47:43.388 S D  0.0000130 kg
02/03/2014 21:47:43.486 S D  0.0000130 kg
02/03/2014 21:47:43.582 S D  0.0000131 kg
02/03/2014 21:47:43.679 S D  0.0000131 kg
02/03/2014 21:47:43.775 S D  0.0000131 kg
02/03/2014 21:47:43.873 S D  0.0000132 kg
02/03/2014 21:47:43.971 S D  0.0000132 kg
02/03/2014 21:47:44.067 S D  0.0000133 kg
02/03/2014 21:47:44.165 S D  0.0000133 kg
02/03/2014 21:47:44.263 S D  0.0000133 kg
02/03/2014 21:47:44.359 S D  0.0000134 kg
02/03/2014 21:47:44.455 S D  0.0000134 kg
02/03/2014 21:47:44.553 S D  0.0000134 kg
02/03/2014 21:47:44.651 S D  0.0000135 kg
02/03/2014 21:47:44.747 S D  0.0000135 kg
02/03/2014 21:47:44.845 S D  0.0000135 kg
02/03/2014 21:47:44.943 S D  0.0000136 kg
02/03/2014 21:47:45.039 S D  0.0000136 kg
02/03/2014 21:47:45.137 S D  0.0000136 kg
02/03/2014 21:47:45.232 S D  0.0000136 kg
02/03/2014 21:47:45.330 S D  0.0000137 kg
02/03/2014 21:47:45.428 S D  0.0000137 kg
02/03/2014 21:47:45.524 S D  0.0000137 kg
02/03/2014 21:47:45.622 S D  0.0000137 kg
02/03/2014 21:47:45.720 S D  0.0000137 kg
02/03/2014 21:47:45.818 S D  0.0000137 kg
02/03/2014 21:47:45.914 S D  0.0000138 kg
02/03/2014 21:47:46.012 S D  0.0000138 kg
02/03/2014 21:47:46.108 S D  0.0000138 kg
02/03/2014 21:47:46.206 S D  0.0000138 kg
02/03/2014 21:47:46.304 S D  0.0000138 kg
02/03/2014 21:47:46.400 S D  0.0000138 kg
02/03/2014 21:47:46.498 S D  0.0000138 kg
02/03/2014 21:47:46.596 S D  0.0000138 kg
02/03/2014 21:47:46.692 S D  0.0000138 kg
02/03/2014 21:47:46.789 S D  0.0000137 kg
02/03/2014 21:47:46.885 S D  0.0000137 kg
02/03/2014 21:47:46.983 S D  0.0000137 kg
02/03/2014 21:47:47.079 S D  0.0000137 kg
02/03/2014 21:47:47.177 S D  0.0000137 kg
02/03/2014 21:47:47.275 S D  0.0000136 kg
02/03/2014 21:47:47.371 S D  0.0000136 kg
02/03/2014 21:47:47.469 S D  0.0000136 kg
02/03/2014 21:47:47.565 S D  0.0000136 kg
02/03/2014 21:47:47.663 S D  0.0000135 kg
02/03/2014 21:47:47.761 S D  0.0000135 kg
02/03/2014 21:47:47.857 S D  0.0000135 kg
02/03/2014 21:47:47.955 S D  0.0000134 kg
02/03/2014 21:47:48.053 S D  0.0000134 kg
02/03/2014 21:47:48.151 S D  0.0000133 kg
02/03/2014 21:47:48.247 S D  0.0000133 kg
02/03/2014 21:47:48.344 S D  0.0000133 kg
02/03/2014 21:47:48.442 S D  0.0000132 kg
02/03/2014 21:47:48.538 S D  0.0000132 kg
02/03/2014 21:47:48.636 S D  0.0000131 kg
02/03/2014 21:47:48.734 S D  0.0000131 kg
02/03/2014 21:47:48.832 S D  0.0000131 kg
02/03/2014 21:47:48.928 S D  0.0000130 kg
02/03/2014 21:47:49.026 S D  0.0000130 kg
02/03/2014 21:47:49.122 S D  0.0000129 kg
02/03/2014 21:47:49.220 S D  0.0000129 kg
02/03/2014 21:47:49.318 S D  0.0000129 kg
02/03/2014 21:47:49.416 S D  0.0000128 kg
02/03/2014 21:47:49.514 S D  0.0000128 kg
02/03/2014 21:47:49.610 S D  0.0000128 kg
02/03/2014 21:47:49.708 S D  0.0000127 kg
02/03/2014 21:47:49.806 S D  0.0000127 kg
02/03/2014 21:47:49.902 S D  0.0000127 kg
02/03/2014 21:47:49.999 S D  0.0000126 kg
02/03/2014 21:47:50.097 S D  0.0000126 kg
02/03/2014 21:47:50.195 S D  0.0000126 kg
02/03/2014 21:47:50.291 S D  0.0000126 kg
02/03/2014 21:47:50.389 S D  0.0000125 kg
02/03/2014 21:47:50.487 S D  0.0000125 kg
02/03/2014 21:47:50.583 S D  0.0000125 kg
02/03/2014 21:47:50.681 S D  0.0000125 kg
02/03/2014 21:47:50.779 S D  0.0000125 kg
02/03/2014 21:47:50.875 S D  0.0000124 kg
02/03/2014 21:47:50.973 S D  0.0000124 kg
02/03/2014 21:47:51.071 S D  0.0000124 kg
02/03/2014 21:47:51.167 S D  0.0000124 kg
02/03/2014 21:47:51.265 S D  0.0000124 kg
02/03/2014 21:47:51.363 S D  0.0000124 kg
02/03/2014 21:47:51.459 S D  0.0000124 kg
02/03/2014 21:47:51.556 S D  0.0000124 kg
02/03/2014 21:47:51.654 S D  0.0000124 kg
02/03/2014 21:47:51.752 S D  0.0000124 kg
02/03/2014 21:47:51.848 S D  0.0000124 kg
02/03/2014 21:47:51.946 S D  0.0000124 kg
02/03/2014 21:47:52.044 S D  0.0000124 kg
02/03/2014 21:47:52.142 S D  0.0000124 kg
02/03/2014 21:47:52.238 S D  0.0000124 kg
02/03/2014 21:47:52.336 S D  0.0000124 kg
02/03/2014 21:47:52.434 S D  0.0000124 kg
02/03/2014 21:47:52.532 S D  0.0000124 kg
02/03/2014 21:47:52.630 S D  0.0000124 kg
02/03/2014 21:47:52.728 S D  0.0000124 kg
02/03/2014 21:47:52.824 S D  0.0000124 kg
02/03/2014 21:47:52.922 S D  0.0000125 kg
02/03/2014 21:47:53.020 S D  0.0000125 kg
02/03/2014 21:47:53.115 S D  0.0000125 kg
02/03/2014 21:47:53.213 S D  0.0000125 kg
02/03/2014 21:47:53.311 S D  0.0000125 kg
02/03/2014 21:47:53.407 S S  0.0000125 kg
02/03/2014 21:47:53.505 S S  0.0000125 kg
02/03/2014 21:47:53.603 S S  0.0000125 kg
02/03/2014 21:47:53.699 S S  0.0000125 kg
02/03/2014 21:47:53.797 S S  0.0000125 kg
02/03/2014 21:47:53.895 S S  0.0000125 kg
02/03/2014 21:47:53.993 S S  0.0000125 kg
02/03/2014 21:47:54.089 S S  0.0000125 kg
02/03/2014 21:47:54.187 S S  0.0000125 kg
02/03/2014 21:47:54.285 S S  0.0000125 kg
02/03/2014 21:47:54.383 S S  0.0000125 kg
02/03/2014 21:47:54.479 S S  0.0000125 kg
02/03/2014 21:47:54.577 S S  0.0000125 kg
02/03/2014 21:47:54.674 S S  0.0000125 kg
02/03/2014 21:47:54.770 S S  0.0000125 kg
02/03/2014 21:47:54.868 S S  0.0000125 kg
02/03/2014 21:47:54.966 S S  0.0000125 kg
02/03/2014 21:47:55.062 S S  0.0000125 kg
02/03/2014 21:47:55.160 S S  0.0000125 kg
02/03/2014 21:47:55.258 S S  0.0000125 kg
02/03/2014 21:47:55.356 S S  0.0000125 kg
02/03/2014 21:47:55.452 S S  0.0000125 kg
02/03/2014 21:47:55.550 S S  0.0000125 kg
02/03/2014 21:47:55.646 S S  0.0000125 kg
02/03/2014 21:47:55.742 S S  0.0000125 kg
02/03/2014 21:47:55.840 S S  0.0000125 kg
02/03/2014 21:47:55.938 S S  0.0000125 kg
02/03/2014 21:47:56.036 S S  0.0000125 kg
02/03/2014 21:47:56.132 S S  0.0000125 kg

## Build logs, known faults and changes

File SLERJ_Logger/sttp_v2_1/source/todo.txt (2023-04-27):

ToDo
- Add statistics and appropriate error reporting so user is aware of input
  data file problems.

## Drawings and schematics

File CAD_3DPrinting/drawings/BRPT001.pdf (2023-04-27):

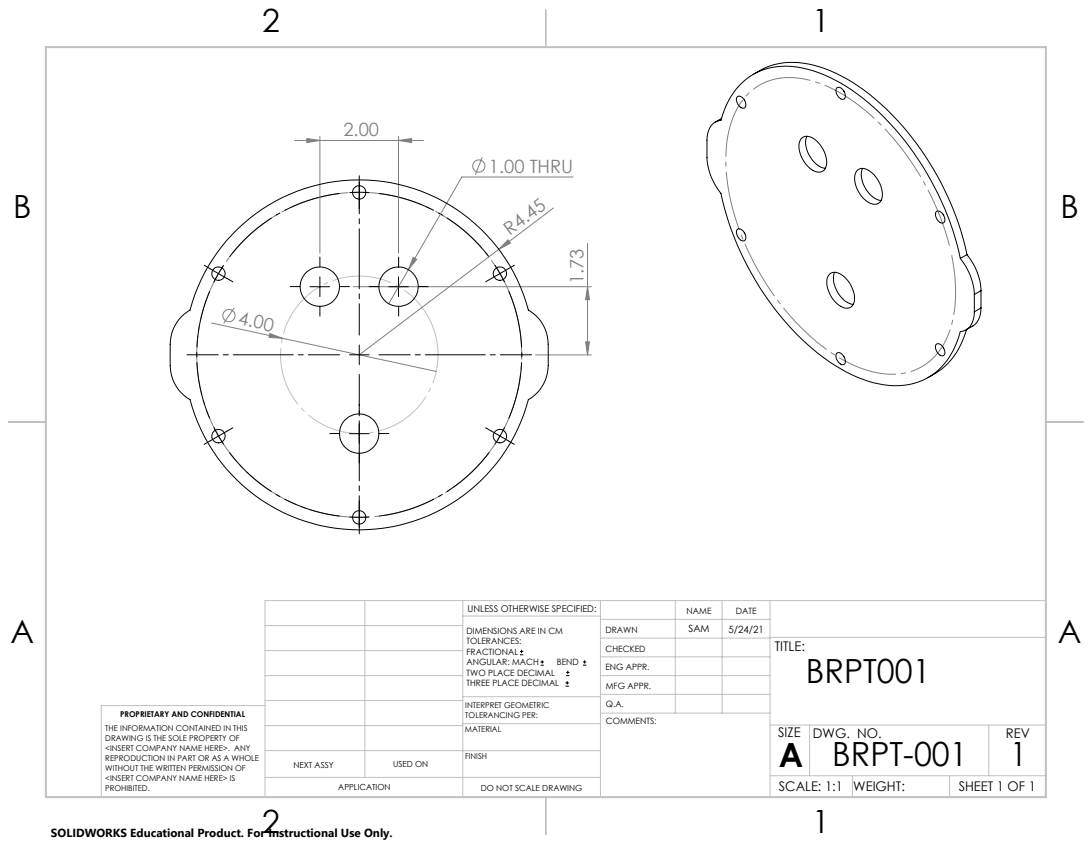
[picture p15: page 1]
1.00 THRU

UNLESS OTHERWISE SPECIFIED: | | NAME | DATE
DIMENSIONS ARE IN CM TOLERANCES: FRACTIONAL ANGULAR: MACH BEND TWO PLACE DECIMAL THREE PLACE DECIMAL | DRAWN | SAM | 5/24/21

CHECKED | | | TITLE: BRPT001

ENG APPR.
MFG APPR.

INTERPRET GEOMETRIC TOLERANCING PER: | Q.A.
MATERIAL | | SIZE A | DWG. NO. BRPT-001 | REV 1

PROPRIETARY AND CONFIDENTIAL
THE INFORMATION CONTAINED IN THIS
DRAWING IS THE SOLE PROPERTY OF
<INSERT COMPANY NAME HERE>. ANY
REPRODUCTION IN PART OR AS A WHOLE
WITHOUT THE WRITTEN PERMISSION OF
<INSERT COMPANY NAME HERE> IS
PROHIBITED.

NEXT ASSY | USED ON | FINISH

APPLICATION | DO NOT SCALE DRAWING | | SCALE: 1:1 | WEIGHT: | SHEET 1 OF 1

SOLIDWORKS Educational Product. For Instructional Use Only.

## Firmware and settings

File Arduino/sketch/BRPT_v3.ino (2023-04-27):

// Include Libraries
#include <Wire.h>
#include <TSYS01.h> // modified TSYS01 library
#include <MS5837.h> // modified MS5837 library

// Define pin for built in LED control
#define LEDpin 13
#define HWSERIAL Serial1 // Turn on hardware serial for TX1/RX1 on Teensy for logging to SLERJ
// Set I2C address for each sensor
MS5837 Psensor;
TSYS01 Tsensor;

String TSYS;
String TBAR02;
String PBAR02;


void setup() {
  Wire.begin();

  Serial.begin(115200); // Initialize serial monitor
  Serial1.begin(115200); // Initialize TX1/RX1
  pinMode(LEDpin, OUTPUT); // Set pinMode for LED control

  // Initialize pressure sensor
  // Returns true if the initialization was succesful
  // We can't continue with the rest of the program unless the sensor works properly
  Psensor.init();
  while (!Psensor.init()) {
    Serial.println("Psensor init FAIL!");
    Serial.print("\n\n\n");
    delay(5000);
  }
  Psensor.setModel(MS5837::MS5837_02BA);
  Psensor.setFluidDensity(1029);
  Psensor.read();
  Serial.println("Pressure sensor init SUCCESS!");
  Serial.print("P = "); Serial.print(Psensor.pressure() / 100.); Serial.println(" mbar \n");
  delay(1000);

  // Initialize temperature sensor
  // Returns true if initialization was successful
  // We can't continue with the rest of the program unless we can initialize the sensor
  Tsensor.init();
  Tsensor.read();

 while ((Tsensor.temperature() < 0) || (Tsensor.temperature() > 100)) {
    Serial.print("Tsensor init FAIL!");
    Tsensor.init();
    Tsensor.read();
    Serial.println("\n\n\n");
    delay(5000);
  }

  Serial.println("Temperature sensor init SUCCESS");
  Serial.print("T = "); Serial.print(Tsensor.temperature()); Serial.println(" C \n");
  delay(1000);

  // Blink 3 times to indicate successful initialization of both sensors
  for (int n = 0; n < 3; n++) {
    for (int r = 0; r <= 255; r++) {
      analogWrite(LEDpin, r);
      delay(1);
    }
    for (int r = 255; r >= 0 ; r--) {
      analogWrite(LEDpin, r);
      delay(1);
    }
  }
  Serial.println("TSYS01 [*C],TBar02 [*C], PBar02 [mbar]");
  Serial1.println("TSYS01 [*C],TBar02 [*C], PBar02 [mbar]");
}

void loop() {
  analogWrite(LEDpin, 255);
  Tsensor.read();
  Psensor.read();
  String TSYS = Tsensor.temperature();
  String TBAR02 = Psensor.temperature() / 100.;
  String PBAR02 = Psensor.pressure() / 100.;
  Serial.print(F("TSYS = "));
  Serial.print(TSYS);
  Serial.println(" *C");

  Serial.print(F("PBar02 = "));
  Serial.print(PBAR02);
  Serial.println(" mbar \n");



  Serial1.println(TSYS + "," + TBAR02 + "," + PBAR02);
//  delay(500);
  analogWrite(LEDpin, 0);
  delay(10);
}

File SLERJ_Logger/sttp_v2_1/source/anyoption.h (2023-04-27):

#ifndef _ANYOPTION_H
#define _ANYOPTION_H

#include <iostream>
#include <fstream>
#include <stdlib.h>
#include <string>
#include <string.h>

#define COMMON_OPT 	1
#define COMMAND_OPT 	2
#define FILE_OPT 	3
#define COMMON_FLAG 	4
#define COMMAND_FLAG 	5
#define FILE_FLAG 	6

#define COMMAND_OPTION_TYPE  	1
#define COMMAND_FLAG_TYPE 	2
#define FILE_OPTION_TYPE  	3
#define FILE_FLAG_TYPE 		4 
#define UNKNOWN_TYPE 		5

#define DEFAULT_MAXOPTS 	10
#define MAX_LONG_PREFIX_LENGTH 	2

#define TRUE_FLAG "true" 

using namespace std;

class AnyOption 
{

public: /* the public interface */
	AnyOption();
	AnyOption(int maxoptions ); 
	AnyOption(int maxoptions , int maxcharoptions); 
	~AnyOption();

	/* 
         * following set methods specifies the  
	 * special characters and delimiters 
	 * if not set traditional defaults will be used
         */

	void setCommandPrefixChar( char _prefix );   /* '-' in "-w" */
	void setCommandLongPrefix( char *_prefix );  /* '--' in "--width" */
	void setFileCommentChar( char _comment );    /* '#' in shellscripts */
	void setFileDelimiterChar( char _delimiter );/* ':' in "width : 100" */

	/* 
	 * provide the input for the options
         * like argv[] for commndline and the 
         * option file name  to use;
	 */

	void useCommandArgs( int _argc, char **_argv );
	void useFiileName( const char *_filename );

	/* 
         * turn off the POSIX style options 
         * this means anything starting with a '-' or "--"
         * will be considered a valid option 
         * which alo means you cannot add a bunch of 
         * POIX options chars together like "-lr"  for "-l -r"
         * 
         */

	void noPOSIX();

	/*
         * prints warning verbose if you set anything wrong 
         */
	void setVerbose();


	/* 
         * there are two types of options  
         *
         * Option - has an associated value ( -w 100 )
         * Flag  - no value, just a boolean flag  ( -nogui )
         * 
	 * the options can be either a string ( GNU style )
         * or a character ( traditional POSIX style ) 
         * or both ( --width, -w )
         *
         * the options can be common to the commandline and 
         * the optionfile, or can belong only to either of 
         * commandline and optionfile
         *
         * following set methods, handle all the aboove 
	 * cases of options.
         */

	/* options comman to command line and option file */
	void setOption( const char *opt_string );
	void setOption( char  opt_char );
	void setOption( const char *opt_string , char opt_char );
	void setFlag( const char *opt_string );
	void setFlag( char  opt_char );
	void setFlag( const char *opt_string , char opt_char );

	/* options read from commandline only */
	void setCommandOption( const char *opt_string );
	void setCommandOption( char  opt_char );
	void setCommandOption( const char *opt_string , char opt_char );
	void setCommandFlag( const char *opt_string );
	void setCommandFlag( char  opt_char );
	void setCommandFlag( const char *opt_string , char opt_char );

	/* options read from an option file only  */
	void setFileOption( const char *opt_string );
	void setFileOption( char  opt_char );
	void setFileOption( const char *opt_string , char opt_char );
	void setFileFlag( const char *opt_string );
	void setFileFlag( char  opt_char );
	void setFileFlag( const char *opt_string , char opt_char );

	/*
         * process the options, registerd using 
         * useCommandArgs() and useFileName();
         */
	void processOptions();  
	void processCommandArgs();
	void processCommandArgs( int max_args );
	bool processFile();

	/*
         * process the specified options 
         */
	void processCommandArgs( int _argc, char **_argv );
	void processCommandArgs( int _argc, char **_argv, int max_args );
	bool processFile( const char *_filename );
	
	/*
         * get the value of the options 
	 * will return NULL if no value is set 
         */
	char *getValue( const char *_option );
	bool  getFlag( const char *_option );
	char *getValue( char _optchar );
	bool  getFlag( char _optchar );

	/*
	 * Print Usage
	 */
	void printUsage();
	void printAutoUsage();
  void addUsage(const char *fmt, ...);
	void printHelp();
        /* print auto usage printing for unknown options or flag */
	void autoUsagePrint(bool flag);
	
	/* 
         * get the argument count and arguments sans the options
         */
	int   getArgc();
	char* getArgv( int index );
	bool  hasOptions();

private: /* the hidden data structure */
	int argc;		/* commandline arg count  */
	char **argv;  		/* commndline args */
	const char* filename; 	/* the option file */
	char* appname; 	/* the application name from argv[0] */

	int *new_argv; 		/* arguments sans options (index to argv) */
	int new_argc;   	/* argument count sans the options */
	int max_legal_args; 	/* ignore extra arguments */


	/* option strings storage + indexing */
	int max_options; 	/* maximum number of options */
	const char **options; 	/* storage */
	int *optiontype; 	/* type - common, command, file */
	int *optionindex;	/* index into value storage */
	int option_counter; 	/* counter for added options  */

	/* option chars storage + indexing */
	int max_char_options; 	/* maximum number options */
	char *optionchars; 	/*  storage */
	int *optchartype; 	/* type - common, command, file */
	int *optcharindex; 	/* index into value storage */
	int optchar_counter; 	/* counter for added options  */

	/* values */
	char **values; 		/* common value storage */
	int g_value_counter; 	/* globally updated value index LAME! */

	/* help and usage */
  std::string usage;    /* usage */

	bool command_set;	/* if argc/argv were provided */
	bool file_set;		/* if a filename was provided */
	bool mem_allocated;     /* if memory allocated in init() */
	bool posix_style; 	/* enables to turn off POSIX style options */
	bool verbose;		/* silent|verbose */
	bool print_usage;	/* usage verbose */
	bool print_help;	/* help verbose */
	
	char opt_prefix_char;		/*  '-' in "-w" */
	char long_opt_prefix[MAX_LONG_PREFIX_LENGTH]; /* '--' in "--width" */
	char file_delimiter_char;	/* ':' in width : 100 */
	char file_comment_char;		/*  '#' in "#this is a comment" */
	char equalsign;
	char comment;
	char delimiter;
	char endofline;
	char whitespace;
	char nullterminate;

	bool set;   //was static member
	bool once;  //was static member
	
	bool hasoptions;
	bool autousage;
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

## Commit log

2024-09-25 Updated assembly guide, SRD notes and edits
2024-09-25 Delete AssemblyGuide/SRD_Assembly.pdf
    file had yet to be updated.
